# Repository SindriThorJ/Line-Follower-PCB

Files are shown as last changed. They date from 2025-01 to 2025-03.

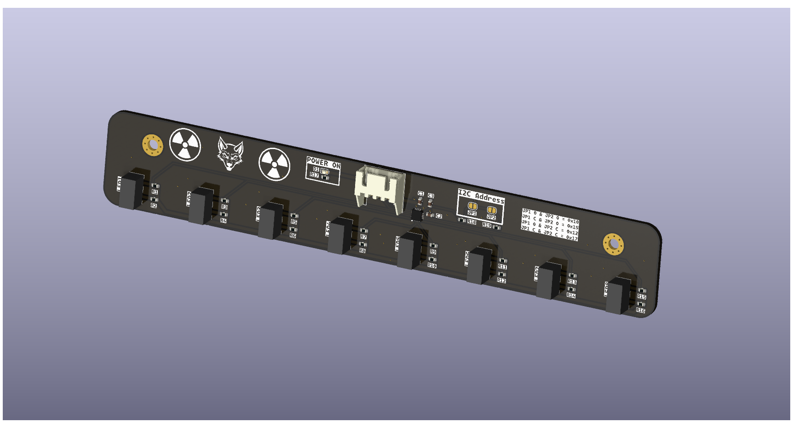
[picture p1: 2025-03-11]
Raytraced - Line Follower Front.png

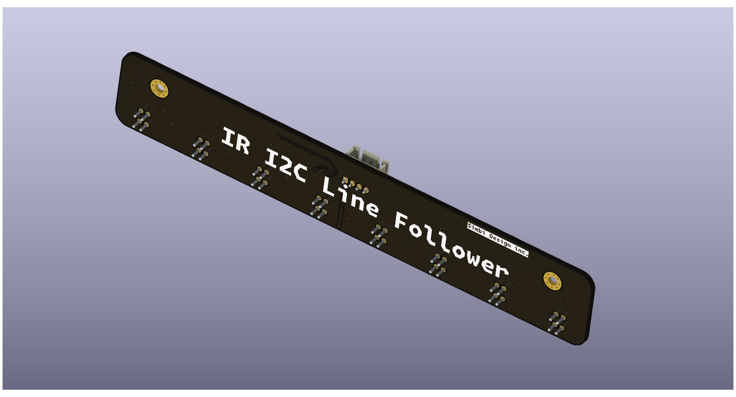
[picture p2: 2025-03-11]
Raytraced - Line Follower Back.png

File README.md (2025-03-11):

This repo is for storing the design files of my PCB based IR line follower, the line follower can have multiple I2C addresses by modifying the solder bridges according to the table on the silkscreen.

Raytraced front view:
Raytraced - Line Follower Front

Raytraced back view:
Raytraced - Line Follower Back

Actual picture of the board: 
Real Life - Line Follower Front

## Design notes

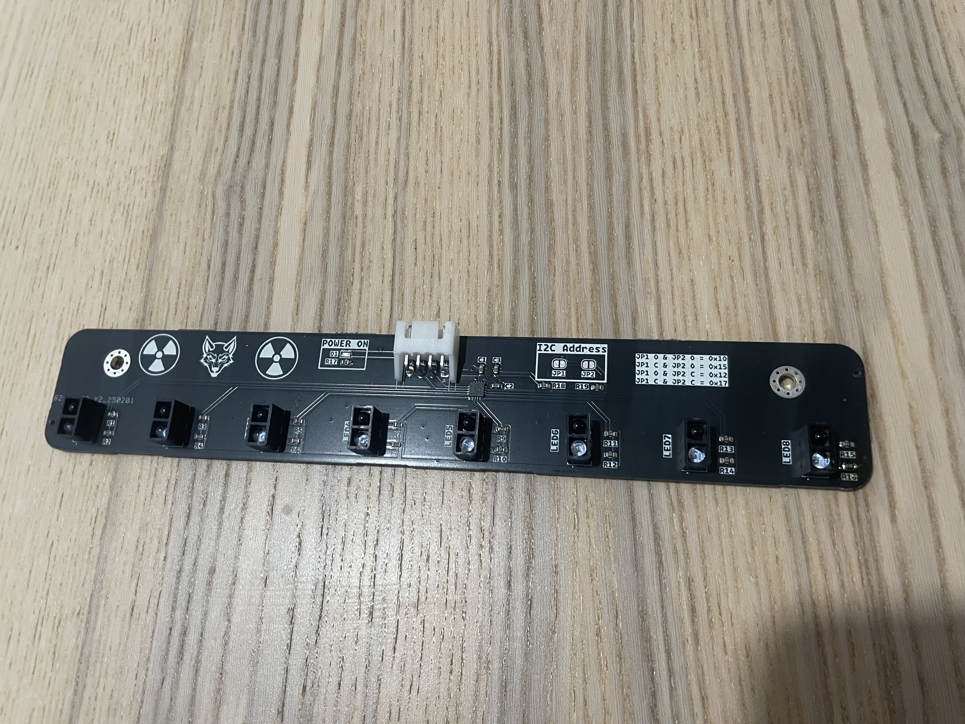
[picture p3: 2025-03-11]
Real Life - Line Follower Front.jpeg

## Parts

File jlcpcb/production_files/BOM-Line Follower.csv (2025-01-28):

Comment | Designator | Footprint | LCSC
Conn_01x04 |  | JST_XH_S4B-XH-A-1_1x04_P2.50mm_Horizontal | C157925
1uF | C1,C2,C3 | C_0603_1608Metric | C15849
100R | R10,R12,R14,R16,R2,R4,R6,R8 | R_0603_1608Metric | C22775
LED | D1 | LED_0603_1608Metric | C2286
470R | R17 | R_0603_1608Metric | C23179
10k | R1,R11,R13,R15,R3,R5,R7,R9 | R_0603_1608Metric | C25804
TLA2528IRTER | U1 | QFN50P300X300X80-17N-D | C2866175
33k | R18 | R_0603_1608Metric | C31850
33k | R19 | R_0603_1608Metric | C4216
ITR9909 | LED2,LED4,LED6,LED8 | ITR9909 | C53399

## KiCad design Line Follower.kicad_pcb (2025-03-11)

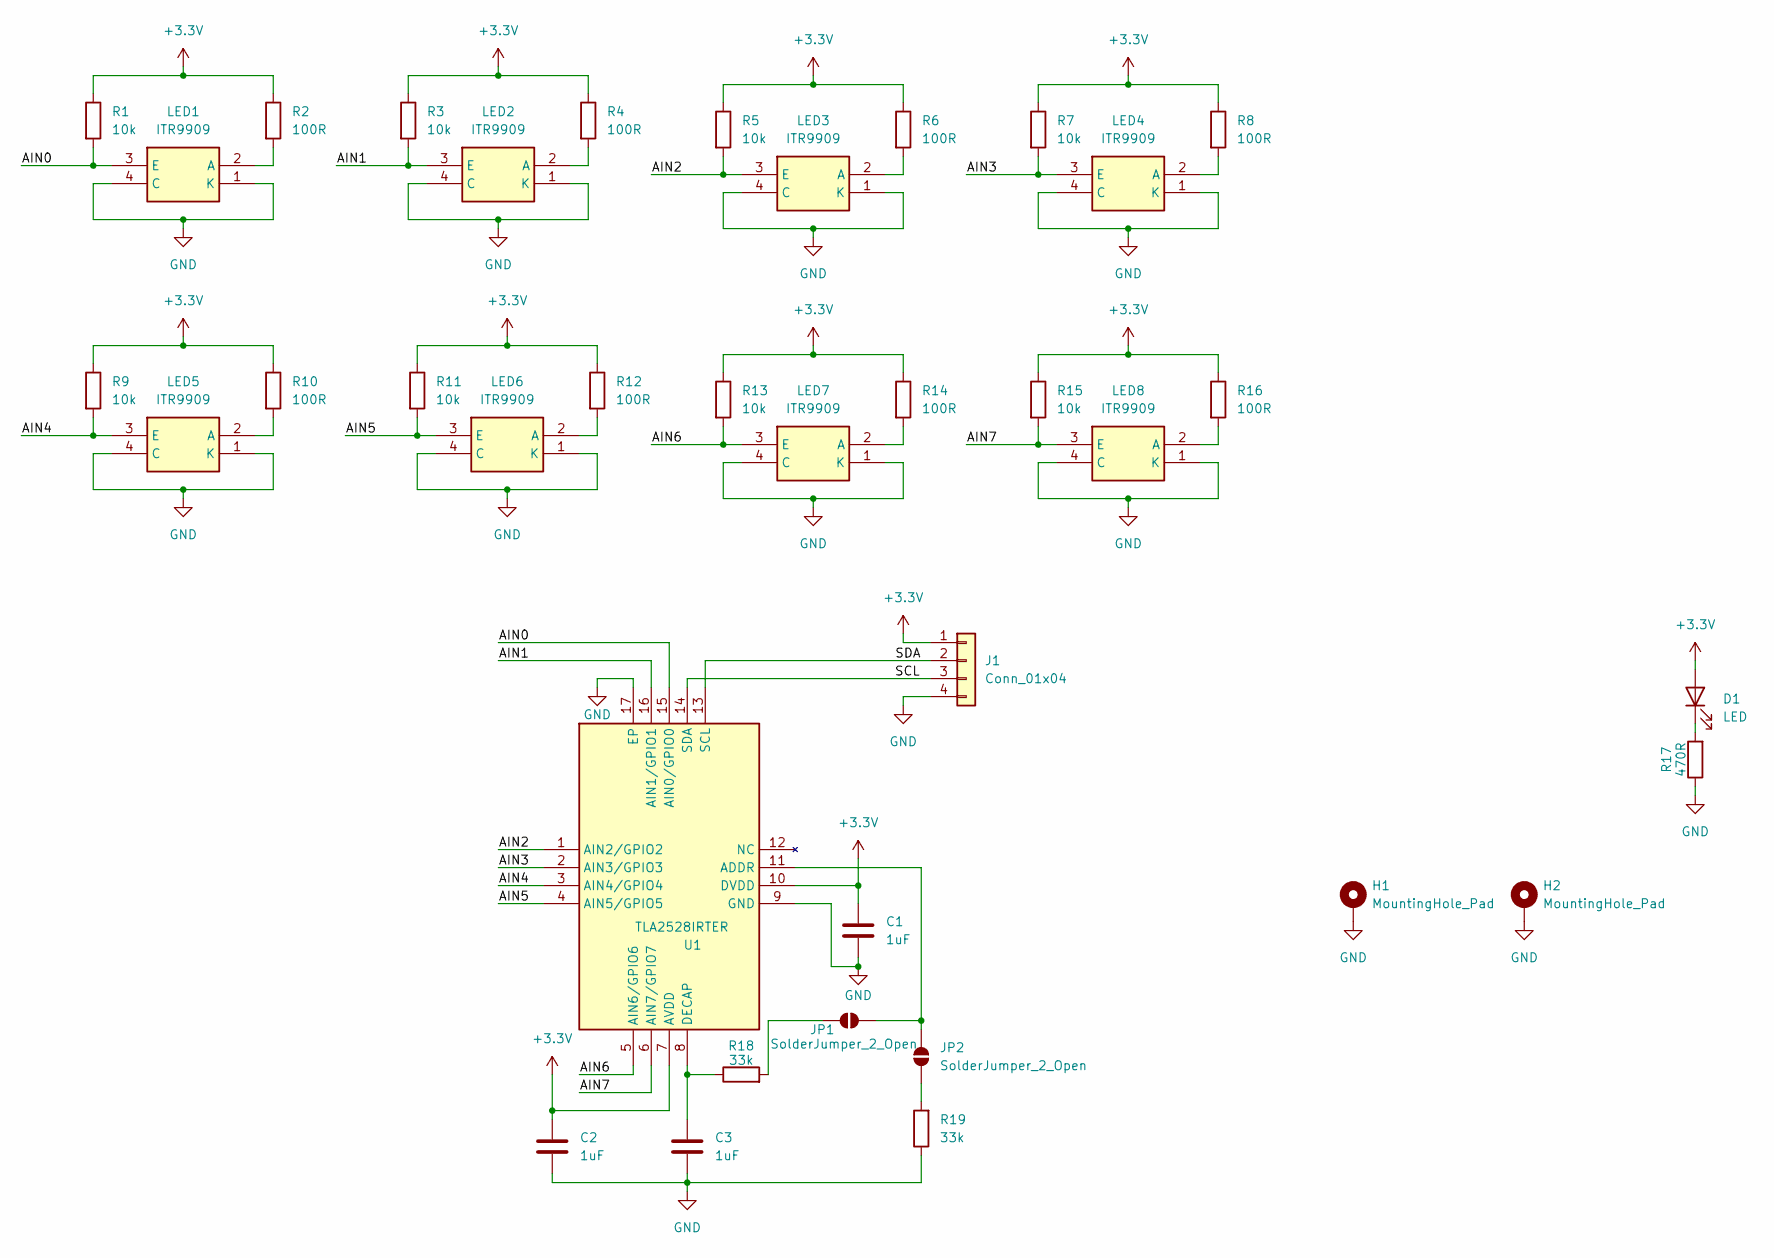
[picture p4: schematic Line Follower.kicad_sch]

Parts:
C1, C2, C3: 1uF; C_0603_1608Metric
D1: LED; LED_0603_1608Metric
H1, H2: MountingHole_Pad; MountingHole_3.2mm_M3_Pad_Via
J1: Conn_01x04; JST_XH_S4B-XH-A-1_1x04_P2.50mm_Horizontal
JP1, JP2: SolderJumper_2_Open; SolderJumper-2_P1.3mm_Open_RoundedPad1.0x1.5mm
LED1, LED2, LED3, LED4, LED5, LED6, LED7, LED8: ITR9909; Manufacturer_Part_Number ITR9909
R1, R3, R5, R7, R9, R11, R13, R15: 10k; R_0603_1608Metric
R2, R4, R6, R8, R10, R12, R14, R16: 100R; R_0603_1608Metric
R17: 470R; R_0603_1608Metric
R18, R19: 33k; R_0603_1608Metric
U1: TLA2528IRTER; QFN50P300X300X80-17N-D; Manufacturer_Part_Number TLA2528IRTER; Mouser Part Number 595-TLA2528IRTER

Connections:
+3.3V: C1.1, C2.1, D1.2 (A), J1.1, R1.1, R2.1, R3.1, R4.1, R5.1, R6.1, R7.1, R8.1, R9.1, R10.1, R11.1, R12.1, R13.1, R14.1, R15.1, R16.1, U1.7 (AVDD), U1.10 (DVDD)
/AIN0: LED1.3 (E), R1.2, U1.15 (AIN0/GPIO0)
/AIN1: LED2.3 (E), R3.2, U1.16 (AIN1/GPIO1)
/AIN2: LED3.3 (E), R5.2, U1.1 (AIN2/GPIO2)
/AIN3: LED4.3 (E), R7.2, U1.2 (AIN3/GPIO3)
/AIN4: LED5.3 (E), R9.2, U1.3 (AIN4/GPIO4)
/AIN5: LED6.3 (E), R11.2, U1.4 (AIN5/GPIO5)
/AIN6: LED7.3 (E), R13.2, U1.5 (AIN6/GPIO6)
/AIN7: LED8.3 (E), R15.2, U1.6 (AIN7/GPIO7)
/SCL: J1.3, U1.14 (SDA)
/SDA: J1.2, U1.13 (SCL)
GND: C1.2, C2.2, C3.2, H1.1, H2.1, J1.4, LED1.1 (K), LED1.4 (C), LED2.1 (K), LED2.4 (C), LED3.1 (K), LED3.4 (C), LED4.1 (K), LED4.4 (C), LED5.1 (K), LED5.4 (C), LED6.1 (K), LED6.4 (C), LED7.1 (K), LED7.4 (C), LED8.1 (K), LED8.4 (C), R17.1, R19.1, U1.9 (GND), U1.17 (EP)
unnamed: D1.1 (K), R17.2
unnamed: JP1.1 (A), JP2.2 (B), U1.11 (ADDR)
unnamed: JP1.2 (B), R18.2
unnamed: JP2.1 (A), R19.2
unnamed: LED1.2 (A), R2.2
unnamed: LED2.2 (A), R4.2
unnamed: LED3.2 (A), R6.2
unnamed: LED4.2 (A), R8.2
unnamed: LED5.2 (A), R10.2
unnamed: LED6.2 (A), R12.2
unnamed: LED7.2 (A), R14.2
unnamed: LED8.2 (A), R16.2
unnamed: C3.1, R18.1, U1.8 (DECAP)

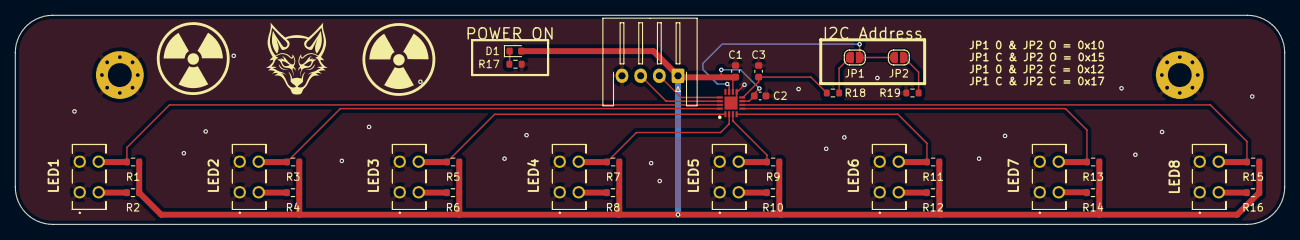
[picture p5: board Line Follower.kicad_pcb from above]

Board: 2 copper layers, 170.0 x 28.0 mm, 37 parts (0 on the bottom side), 25 nets.

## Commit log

2025-01-28 PCB ordered from JLCPCB
    [BOM-Line Follower.csv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]
2025-03-11 Added images..
    [Line Follower.kicad_pcb, Line Follower.kicad_sch]
2025-03-11 Added image of the actual board.
